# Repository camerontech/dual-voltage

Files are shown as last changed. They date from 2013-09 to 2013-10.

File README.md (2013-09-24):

5v & 3.3v Dual Voltage Regulator
================================
This board accepts a reasonable input (20v or less) and provides both 5v and 3.3v regulated outputs.

Parts
-----
Here's the parts I use when building this myself:

**10uF Capacitors**: [DigiKey Part P975-ND](http://www.digikey.com/product-search/en/capacitors/aluminum-capacitors/131081?k=P975-ND)

**0.1uF Capacitors**: [DigiKey Part 399-4266-ND](http://www.digikey.com/product-detail/en/C320C104M5U5TA/399-4266-ND/818042)

**5v Linear Regulator**: [DigiKey Part MC7805CT-BPMS-ND](http://www.digikey.com/product-detail/en/MC7805CT-BP/MC7805CT-BPMS-ND/804682)

**3.3v Linear Regulator**: [DigiKey Part 296-21633-5-ND](http://www.digikey.com/product-detail/en/UA78M33CKCS/296-21633-5-ND/1494026)

With these regulators you can run about 1.5A through the 5v output and 0.5A through the 3.3v output.
If you go that high you should seriously think about adding 
[heat sinks](http://www.digikey.com/product-search/en/fans-thermal-management/thermal-heat-sinks/1179752) 
to the regulators. To figure out how much power you're going to turn into heat, check this out: https://www.sparkfun.com/tutorials/217

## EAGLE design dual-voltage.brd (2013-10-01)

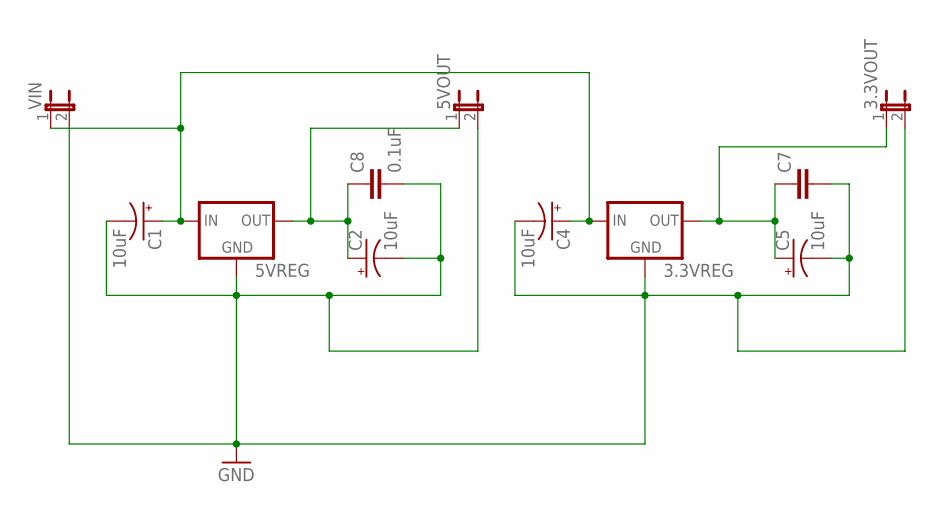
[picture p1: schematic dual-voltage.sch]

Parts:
3.3VOUT, 5VOUT: JUMPER-2PTH; 1X02
3.3VREG, 5VREG: 78XXS
C1, C2, C4, C5: 10uF; CPOL-RADIAL-10UF-25V
C7: CAPPTH2; CAP-PTH-SMALL2
C8: 0.1uF; CAP-PTH-SMALL2
VIN: JUMPER-2PTH; 1X02

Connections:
3.3V: 3.3VOUT.1, 3.3VREG.OUT, C5.1 (+), C7.1
5V: 5VOUT.1, 5VREG.OUT, C2.1 (+), C8.1
GND: 3.3VOUT.2, 3.3VREG.GND, 5VOUT.2, 5VREG.GND, C1.2 (-), C2.2 (-), C4.2 (-), C5.2 (-), C7.2, C8.2, VIN.2
unnamed: 3.3VREG.IN, 5VREG.IN, C1.1 (+), C4.1 (+), VIN.1

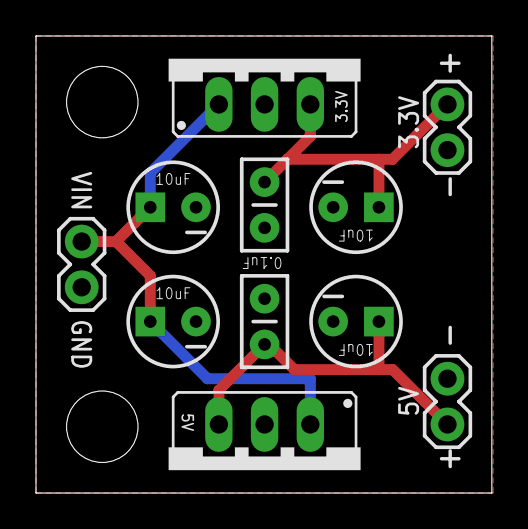
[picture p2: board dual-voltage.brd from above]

Board: 2 copper layers, 25.3 x 25.4 mm, 11 parts (0 on the bottom side), 4 nets.

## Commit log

2013-09-19 Trace updates for new 3.3v regulator
    [dual-voltage.brd, dual-voltage.sch]
2013-09-20 Updates voltage in/out jumpers to SparkFun components, updates 0.1uF capacitor footprint to SparkFun, bumps version to 1.1.0
    [dual-voltage.brd, dual-voltage.sch]
2013-09-25 Set silkscreen labels to 15%
    [dual-voltage.brd]
2013-10-01 Shrink screw holes to 5/32, bump to 1.1.1
    [dual-voltage.brd]

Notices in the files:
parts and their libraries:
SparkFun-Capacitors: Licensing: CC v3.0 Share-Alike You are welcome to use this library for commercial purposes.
